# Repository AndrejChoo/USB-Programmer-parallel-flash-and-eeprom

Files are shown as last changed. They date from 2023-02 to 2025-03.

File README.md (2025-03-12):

# USB-Programmer-parallel-flash-and-eeprom
USB программатор параллельных Flash, EPROM, EEPROM, микроконтроллеров AVR (в том числе AT89CXX) в режиме высоковольтного параллельного программирования основанный на STM32.

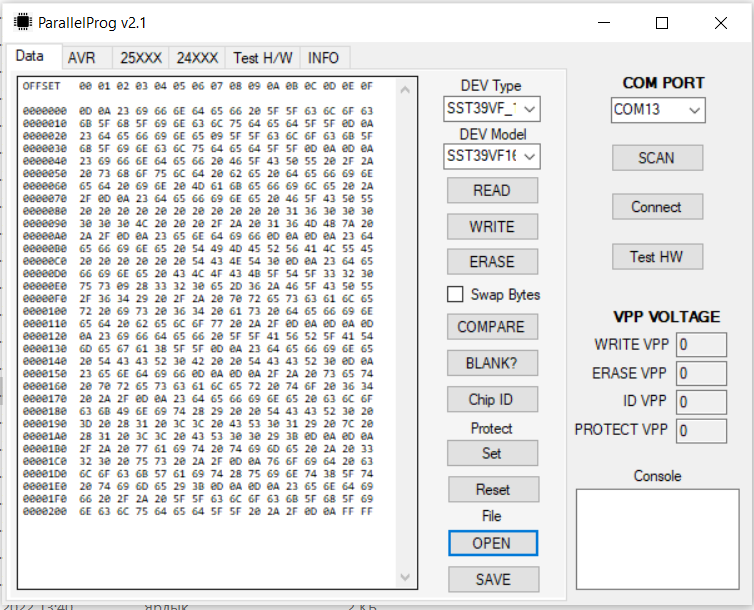
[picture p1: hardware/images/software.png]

# 9.04.2023
На данный момент исправлено множество ошибок в основном в прошивке платы-программатора. 
Немного доработан софт, исправлены некоторые ошибки во вкладке "TestH/W", также там добавлена функция проверки старшего байта данных (D15:8). Исправлена ошибка вылета программы при отключении COM порта (при нажатии на "Disconnect"). Но многие исключения до сих пор ещё не обрабатываются, например при введении некорректных данных в окошки с HEX числами.
Также добавлена прошивка для STM32F103Vxx (запускается также и на 103ZGT в 144 выводном корпусе). Возможно, добавлю прошивку для STM32F407V.
Мною на данный момент лично протестированы запись/чтение/стирание следующих чипов памяти:
8bit:
-W49F020;
-SST39VF040;
-AM29F040;
-W29C040;
-AT28C64;
16bit:
-MX29L3211;
-MX29LV320;
-SST39VF1601;
Протестирована работа программирования AVR в параллельном (высоковольтном) режиме, в том числе в 8-ногих корпусах.

# 10.04.2023
Добавлена поддержка:
8bit:
-W39V040 HUB Flash;
-AT49Fxxx;
16bit:
-M29Wxxx;
-S29ALxxx;
Микросхемы памяти любых семейств большего или меньшего объёма легко добавляются путём редактирования xml файлов в папке программатора.
Также теперь доступна возможность добавления новых чипов памяти без внесения изменений в код программы и прошивку программатора (каким образом это сделать, читайте в "help.txt" файле). Добавлять можно не любые чипы, а только те, у которых алгоритмы чтения/записи/стирания аналогичны с таковыми у уже поддерживаемых.

# 11.04.2023
Добавлена поддержка хабовой флешки PM29FLxxx.
Также навёл порядок в папке адаптеров, добавил к ним минимальное описание.

# 18.04.2023
Изменён алгоритм работы кнопки "Compare", теперь нет необходимости читать чип перед сравнением, это делается автоматически.
Добавлена функция "Blank check", теперь не надо рассматривать прочитанный hex на ячейки, отличные от 0xFF. Чтение также происходит автоматически по нажатию кнопки "Blank?".

# 19.04.2023
Добавлена функция "Swap Byte" для возможности менять местами каждые чётный и нечётный байт записываемого файла. Возможно пригодится для для работы с 16-битными флешками.

# 23.04.2023 
Добавлена поддержка EPROM 27C256/27C512. Работа с 256 проверена на однократно программируеммой AM27C256, работа с 512 пока в железе на проверена, теоретически должны шиться. Пока не добавлена функция стирания для электрически стираемых моделей типа W27C, SST27SF. Добавлю позже, когда получу рабочие образцы. Также должны работать и УФ стираемые модели при условии установки нужного уровня напряжения VPP. Платы переходников также добавлены в папку "PCB/Adapters". Будьте внимательны с джамперами.

# 26.04.2023
Переработал основную плату программатора: добавлен один джампер (переключение адресной линии А18 между А18 и VPP для программирования некоторых EPROM 27С в корпусе DIP32 в переходнике DIP32 для флешек 29x); добавлена разводка для транзисторных ключей управления напряжением VPP параллельно с разводкой под реле; и самое интересное - добавлена разводка для преобразователя напряжения от ШИМ самого микроконтроллера с возможностью контроля напряжения по АЦП для автоматической установки уровня напряжения VPP (параллельно сохранена разводка для преобразователя на MC34063). Схему, прошивки и софт пока готовлю к релизу. Всё будет работать и на старой версии платы.

# 2.05.2023
Добавлена обработка некоторых внештатных событий в программе для предотвращения её "аварийного" завершения.
Добавлен новый переходник DIP32 для EEPROM 27x010, 27x020, 27x040. Обновление софта и прошивки будут в ближайшее время, когда получу образцы для тестов.

# 3.05.2023
Проверена работа программатора с UV EPROM M27C256 и FM27C010 (новый адаптер DIP32  для EPROM). Всё шьётся отлично, внешнее питание VCC не потребовалось, прошивается и при 5 Вольтах. Прошивки и софт обновлены.

# 4.05.2023
Добавлен новый адаптер для 16-битных EPROM и EEPROM типа M27C800, MX29F1615 в корпусе DIP42. В софт и прошивку добавлена поддержка MX29F1615, позже добавлю поддержку M27С800, когда получу образец на тесты.

# 6.05.2023
Добавлена поддержка микроконтроллеров AT89C51/52 в режиме высоковольтного параллельного программирования. Также добавлен адаптер для данных микроконтроллеров в корпусе DIP40 и схема адаптера. 
Проверена работа с UV EPROM AM27C010 - прошивается корректно. 

# 7.05.2023
Добавлена поддержка микроконтроллеров AT89C1051/2051/4051. Также добавлен адаптер для этих МК в корпусе DIP20.

# 11.05.2023
На этот раз - масштабное обновление. Добавлен и опробован новый дискретный модуль повышающего DC-DC преобразователя с цифровым управлением для автоматической установки напряжения VPP. От идеи преобразователя на самом STM я решил отказаться, так как непрерывная коррекция напряжения отнимала бы валовую долю процессорного времени. Поэтому преобразователь был выполнен в виде отдельного модуля, который устанавливается на основную плату в виде "бутерброда" (смотрите инструкцию по модификации основной платы в папке "Hardware"). Позже добавлю новую разводку платы уже с новым преобразователем.
Софт и прошивки обновлены. Старые версии платы также будут без проблем работать с новым софтом и прошивками.
В программе добавлена новая функция во вкладке "Test HW", которая позволяет установить уровень напряжения VPP и проверить корректность его установки.
Работа нового преобразователя проверена на, наверное, самом "прожорливом" из имеющихся у меня чипе памяти MBM2764, который программируется при уровне VPP - 21 Вольт, прошился успешно. Также проверил работу на AT89C52, тоже всё отлично. Просадок напряжения во время процесса записи нет.

# 12.05.2023
Добавлена новая версия платы (v2.1) с разводкой под новый автоматический преобразователь напряжения. Также исправлены некоторые ошибки. Сделана разводка под транзисторные ключи для коммутации OE и A9 вместо реле (ещё не тестировал, разводка под реле осталась). Также подписал практически все компоненты.
Проверена работа с M27C2001 (2Mx8) - прошилась с первого раза без ошибок.

# 28.05.2023
Наконец-то окончательно избавился от реле. Теперь вместо реле используются транзисторные ключи, что значительно снижает помехи по питанию во время срабатывания реле. Работа опробована на самых требовательных к VPP микросхемах EPROM. Схему модификации смотрите в разделе "Hardware". В последних двух версиях платы разводка под ключи вместо реле уже есть.
Также была проверена работа с электрически стираемыми EEPROM SST27SF512, всё работает отлично. Должны также работать W27C512, они программируются точно также. К сожалению те образцы, что я получил от китайских "товарищей" с Али оказались нерабочими, так что проверить не на чем. 
Прошивка и софт остались прежними, за исключением файла "x27x512.xml", он дополнен новыми моделями микросхем памяти.

# 1.06.2023
Немного подкорректировал разводку последней версии платы: перенёс USB разъём на верхнюю сторону платы (разводка под разъём на нижней стороне также осталась). Правда, его расположение не очень удобное - на углу платы. Добавлены перемычки на пины питания для возможности установки STM32F407 (есть отличия по 1 пину на стороне 1-25). Также сделал по толще некоторые линии питания. Подправил кое-где маску. В остальном без изменений.

# 24.06.2023
Получил платы версии v2.1 с pcbway, собрал и протестировал. Это окончательный вариант платы, больше никаких изменений не будет. Фото платы есть в папке HARDWARE/IMAGES.

# 25.02.2024
Переписал софт на Qt. Теперь есть возможность использовать на Linux. Скомпилировал под Linux x64, Linux aarch64, Windows x64. В Qt версии не реализованы функции вкладки "Test HW". Для запуска на Linux необходимо установить QSerialport, qt-base. Возможно, потребуются ещё какие-то недостающие пакеты. Проверить не могу, так как у меня на всех ОС установлен Qt-creator со всем необходимым. Qt версия для Windows скомпилирована со статическими библиотеками, должна работать "из коробки".
Возможно, особенно на Fedora, будет необходимо предоставит права доступа к /dev/ttyACM0 - пишем в терминале: sudo chmod a+rw /dev/ttyACM0. На Windows Qt-версия работает точно так же, но мне больше нравится C# версия программы.

# 15.11.2024

Разработал упрощённую версию программатора на stm32f103c8t6.

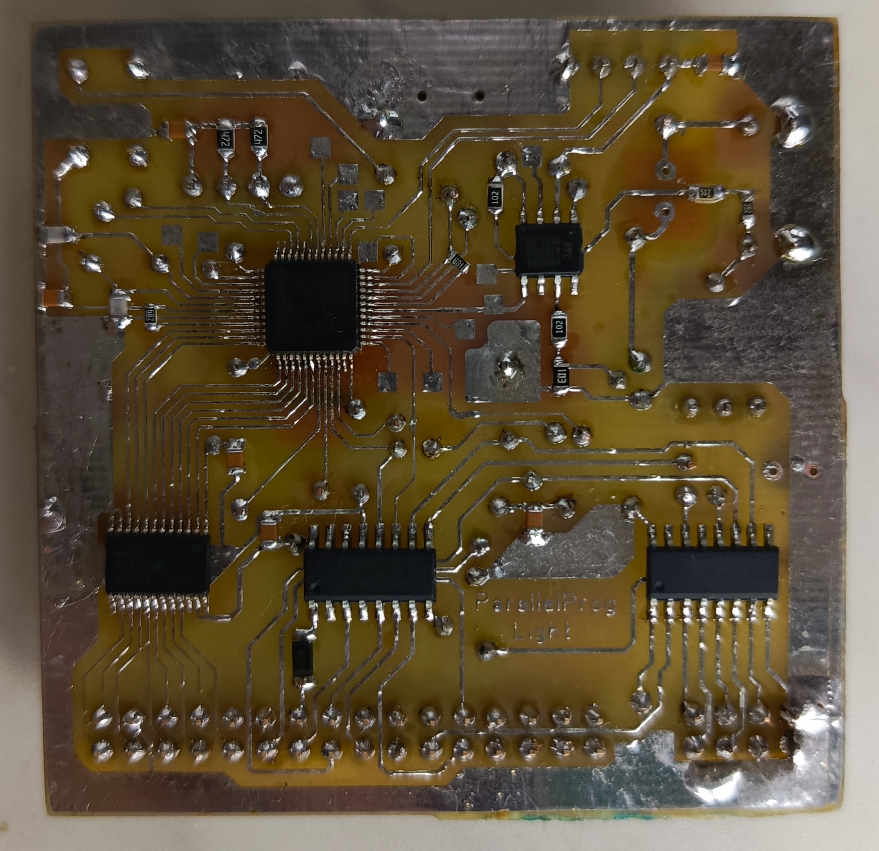
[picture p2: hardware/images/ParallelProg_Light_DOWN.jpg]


Для формирования шины адреса используются три сдвиговых регистра 74hc595. Шина данных только 8 бит, используется всего один буффер 74lvc8t245. Источник высокого напряжения аналогичный "полной версии" программатора - с автоматической установкой уровня VPP. Адаптеры также подходят от "большого брата", кроме 16-битных. Скорость работы программатора несколько ниже, чем у старшей версии ввиду нового последовательного метода формирования сигналов шины адреса, но не критично.
Функционал данной версии программатора, естественно, урезан. Поддерживаются только 8-битные микросхемы памяти. На данный момент прошивка находится в стадии разработки, пока поддерживаются только флешки типа W29Cxxx, AM29Fxxx и им подобные. Буду постепенно добавлять поддержку других микросхем памяти, в первую очередь УФ-стираемых EPROM.

# 18.11.2024

На сегодня в Light-версии программатора опробованы и работают: параллельные флешки W29CXXX, параллельные EEPROM AT28C64/C256, параллельные EEPROM W27C512 (должны работать и УФ-стираемые EPROM типа M27C512), I2C EEPROM серии 24ХХХ (на разъёме I2C). Не проверял, но должны работать флешки типа AM29F010/020/040, SST39F512/010/020/040, AT29FXXX и им подобные восьмибитные.

# 12.03.2025

Выкладываю 3D модели корпуса для полной версии программатора (для платы последней версии), которые разработал и поделился со мной Виктор Черневов. Фото и модели в папке "hardware/case_model".

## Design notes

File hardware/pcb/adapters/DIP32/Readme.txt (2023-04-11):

Адаптер подходит для:
W29CXXX
AM29FXXX
и других с аналогичной распиновкой.

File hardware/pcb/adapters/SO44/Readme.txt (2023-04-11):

Подходит для 16-битных флешек в узких длинных корпусах, например MX29LXXXX.
Перемычку на плате надо запаять к плюсу питания.

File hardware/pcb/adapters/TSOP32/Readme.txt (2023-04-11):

Подходит для флешек как в широком, так и в узком корпусах:
AT49FXXX
SST39SFXXX
и другим с аналогичной распиновкой.

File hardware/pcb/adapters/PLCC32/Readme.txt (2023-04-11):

Подходит для:
W29CXXX
AM29FXXX
AT49FXXX
и других с аналогичной распиновкой.

Джампер в открытом состоянии используется для флешек, у которых вместо A18 - RESET и наоборот.

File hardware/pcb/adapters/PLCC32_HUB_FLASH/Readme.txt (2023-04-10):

Адаптер для хабовых флешек, типа W39Vxxx и им подобных.
При изготовлении платы ЛУТ-ом или фоторезистом - изображение зеркалить!

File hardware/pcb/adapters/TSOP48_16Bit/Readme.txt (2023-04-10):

Адаптер для 48-ногих флешек в корпусе TSOP48 (например, M29W160,S29AL016 и т.д.).
Адаптер сделан для китайского переходника с колодки-быстросъёма на DIP48 (см. фото).
При изготовлении платы ЛУТОМ или фоторезистом изображение не зеркалить, дорожки нарисованы с 
нижней стороны платы.
На плате установлен джампер, переключающий контакт RESET между VCC и VPP. Напряжение VPP нужно для 
снятия защиты с BOOT-блоков некоторых моделей памяти (например, MX29LV320).

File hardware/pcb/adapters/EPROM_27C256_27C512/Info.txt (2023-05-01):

Адаптер DIP28 подходит для 27с64, 27с128, 27с256 (джампер в должны быть установлены в положение "256"), 
для 27с512 (джампер в в положении "512").

Будьте внимательны с джамперами! Их неправильная установка может вывести из 
строя программируемую микросхему!
Внешнее питание к адаптеру подключать не обязательно, некоторые микросхемы памяти программируются
и без повышения VCC (как по datasheet-у).

Напряжение программирования VPP для eprom от разных производителей может отличаться (от 12 вольт до 21,5 вольта).
Необходимый уровень VPP необходимо установит переключением перемычки питания на программаторе либо подбором 
номиналов резисторов преобразователя напряжения.

Резисторы на платах адаптеров в цепи внешнего питания нужно подбирать для получения нужного уровня VCC. Смотрите 
онлайн калькулятор для ams1117-adj.

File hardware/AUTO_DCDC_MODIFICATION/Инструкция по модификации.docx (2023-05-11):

Изначально у меня была идея сделать повышающий преобразователь ресурсами STM-ки, но оказалось, что из-за необходимости частой коррекции уровня напряжения – это бы отнимало валовую часть процессорного времени и тормозило бы процесс программирования непредсказуемым образом.

Поэтому было решено сделать отдельный преобразователь напряжения на микроконтроллере, управляемому по цифровому интерфейсу.

Результат получился отличный. Теперь для установки напряжения нет необходимости менять какие-либо перемычки или подбирать резисторы. Всё происходит автоматически.

Для преобразователя напряжения я выбрал МК STC8G1K08A, так как он очень дёшев, прошивается через обычный USB-UART переходник, имеет компактный SOIC8 корпус.

Преобразователь выполнен на отдельной платке, которая припаивается на основную плату в виде «бутерброда» (см. фото). Для этого необходимо удалить компоненты DC-DC преобразователя на MC34063 с платы (если они установлены), которые расположены в зоне размещения «платки-бутерброда» (см. фото “MOD_Instruct”). Припаять платку преобразователя к основной плате с верхней стороны (там, где расположены разъёмы адаптеров и реле) в точках крепления, обозначенных красным цветом. Три точки (RX,3.3V и RST) необходимо припаять к основной плате проводами в точках, указанных на схеме.

Плата-преобразователь изготовлена в основном на SMD компонентах (кроме электролитов и транзистора). Самое важное при изготовлении – это подобрать правильный дроссель. У меня установлена SMD-гантелька с ~35 витками провода 0,2-0,3 мм. Транзистор в SOT-23 корпусе не сможет раскачать хороший дроссель и скорее всего не даст поднять напряжение выше10-15 вольт, поэтому лучше ставить в корпусе ТО92 (на плате есть разводка под оба корпуса). Диод – любой Шоттки или Fast в подходящем корпусе.

Микроконтроллер прошивается с помощью программы «stc-isp», которую можно скачать на сайте stc-micro через любой USB-UART переходник. При прошивке необходимо установить частоту ядра МК на 30MHz и снять галочку с «Reset pin used as I/O port» (см. картинку “PRG_SETTINGS”). МК можно заменить на более ёмкий STC8G1K17A с той же прошивкой.

Для тестирования работы преобразователя во вкладке тестов основной программы добавлена новая функция установки VPP.

Позже перерисую основную плату сразу с новым преобразователем напряжения на борту.

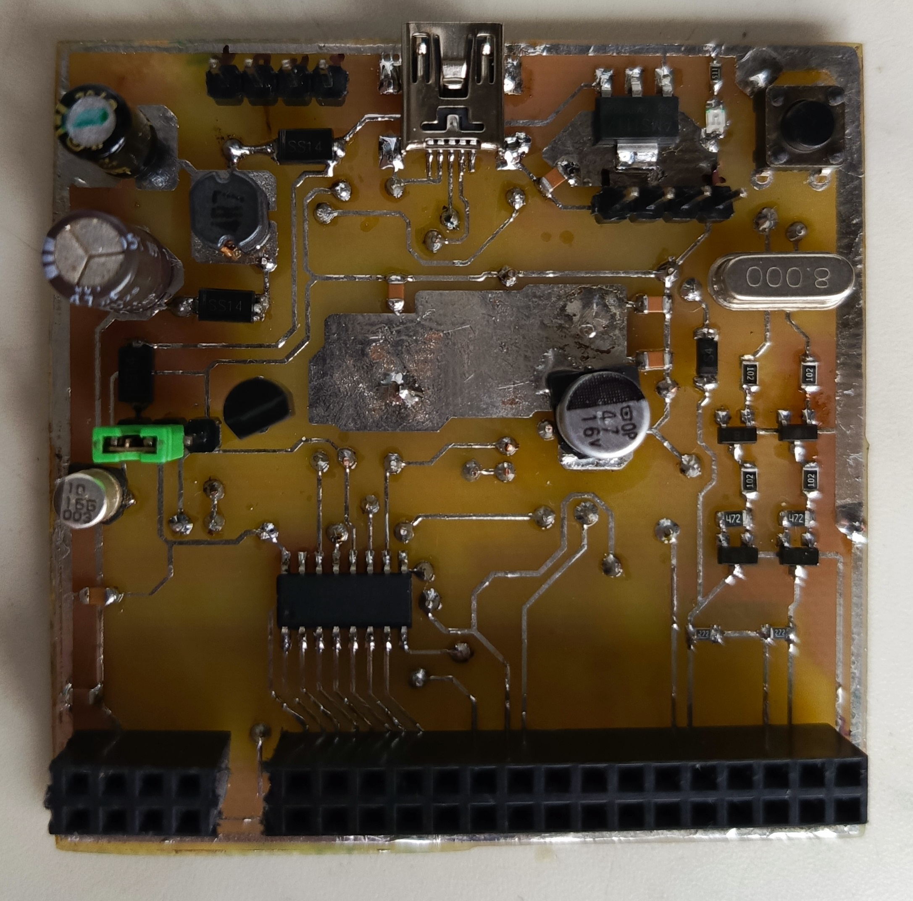
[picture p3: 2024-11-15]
hardware/images/ParallelProg_Light_UP.jpg

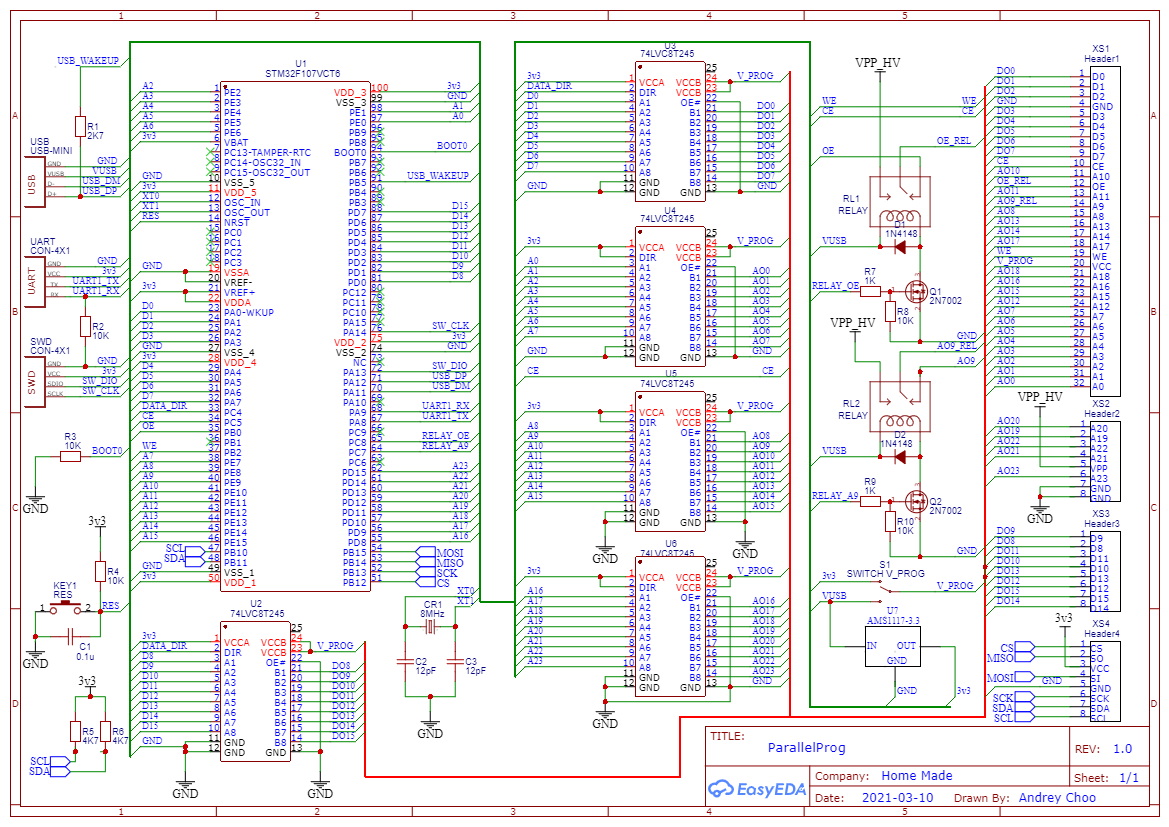
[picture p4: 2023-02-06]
hardware/images/Schematic_ParallelProg_2021-04-04.png

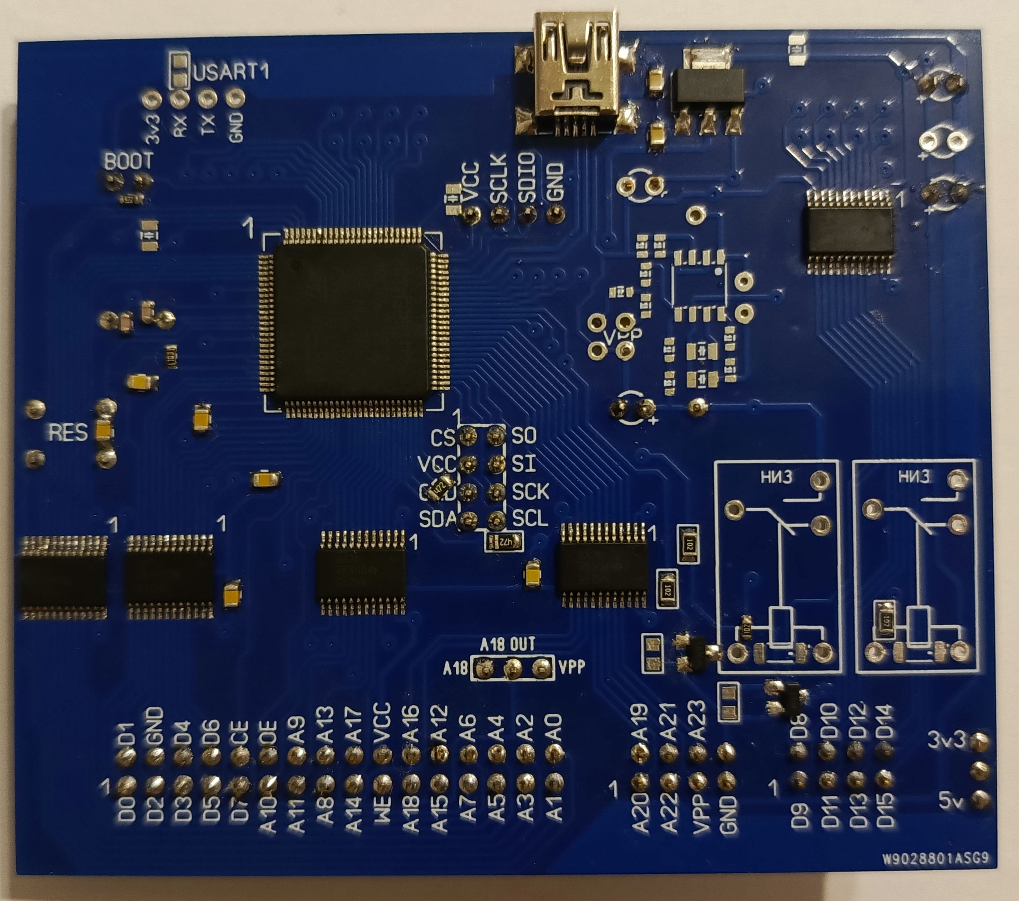
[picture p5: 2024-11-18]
hardware/images/ParallelProg_v2_0_Down.jpg

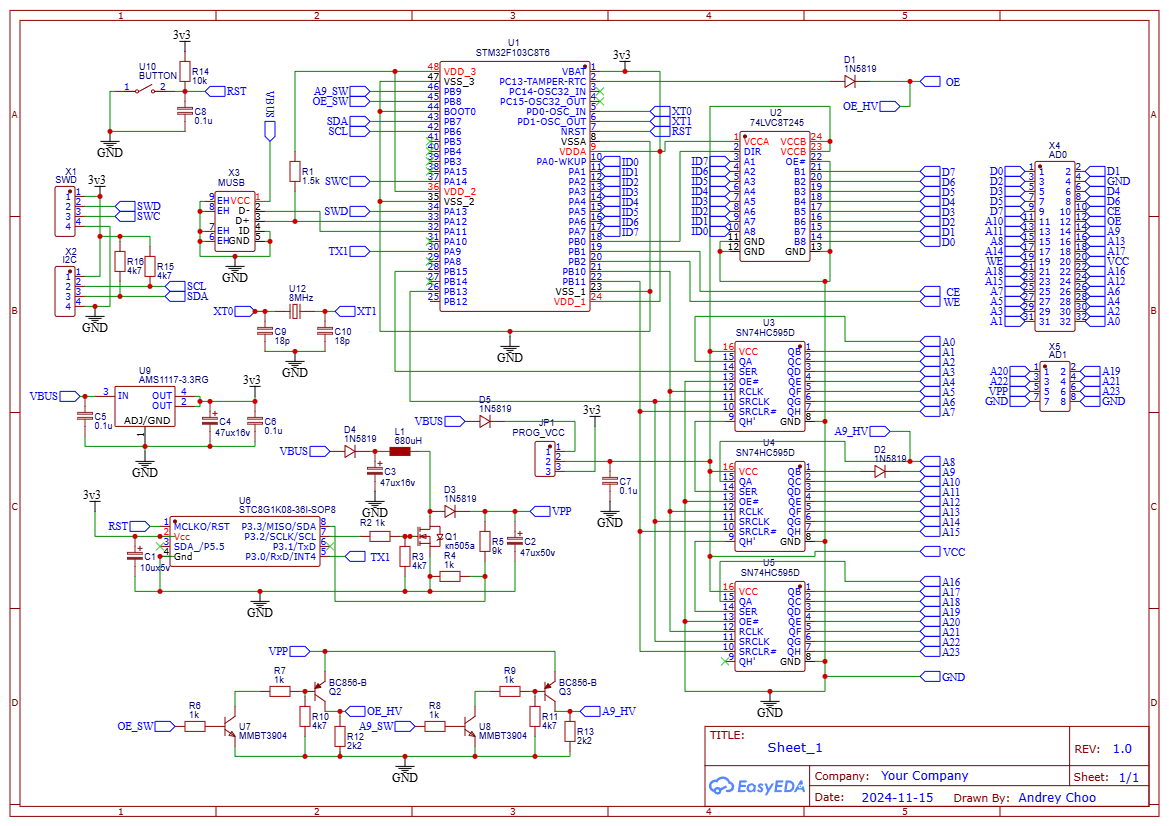
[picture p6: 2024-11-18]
hardware/images/Schematic_ParallelProg_Light_2024-11-18.png

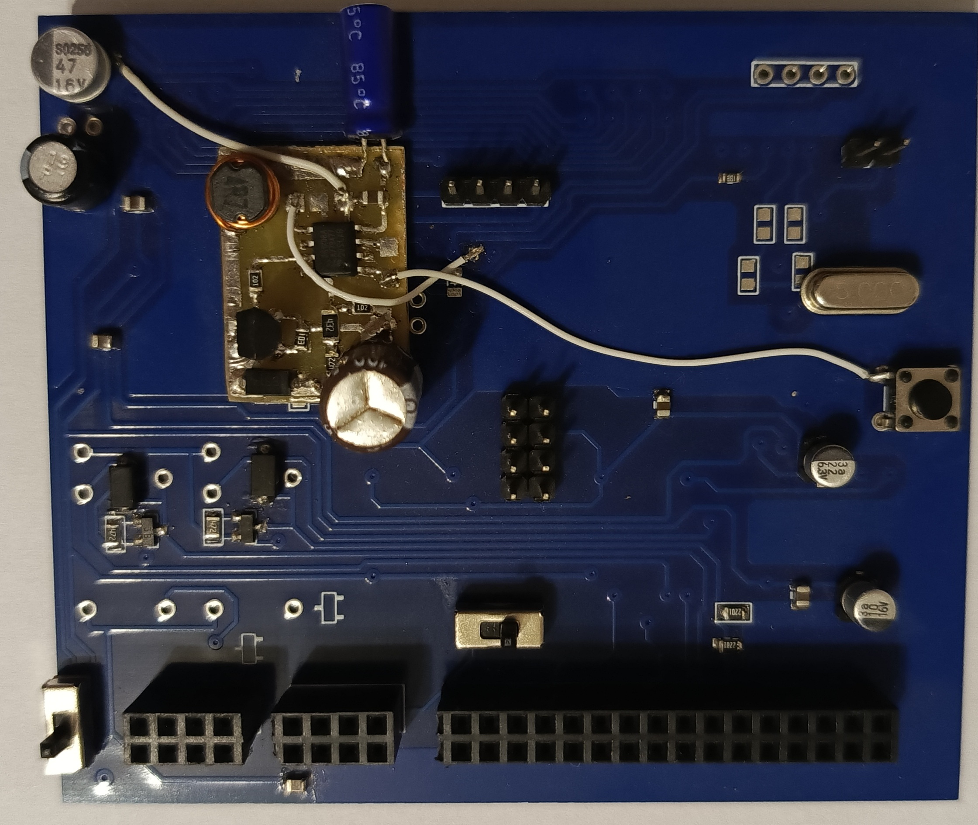
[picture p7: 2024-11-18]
hardware/images/ParallelProg_v2_0_Up.jpg

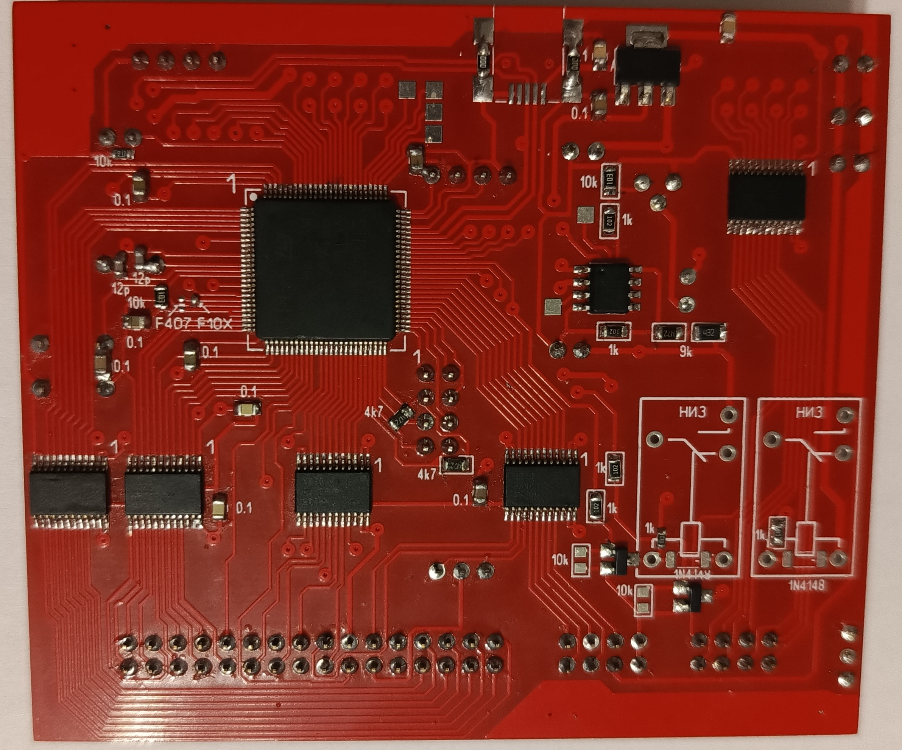
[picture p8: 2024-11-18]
hardware/images/ParallelProg_v2_1_Down.jpg

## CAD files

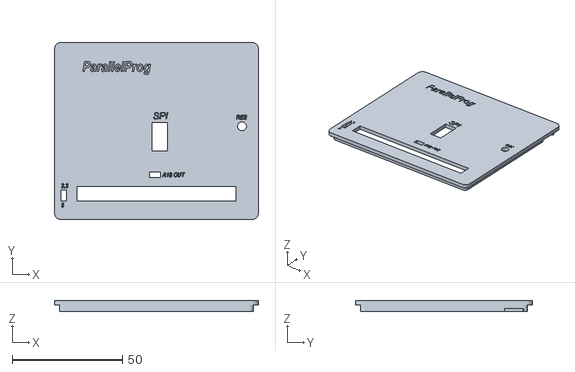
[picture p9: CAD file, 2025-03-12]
hardware/Case_model/Крышка Prog.STL
92.5 x 80.3 x 5.00

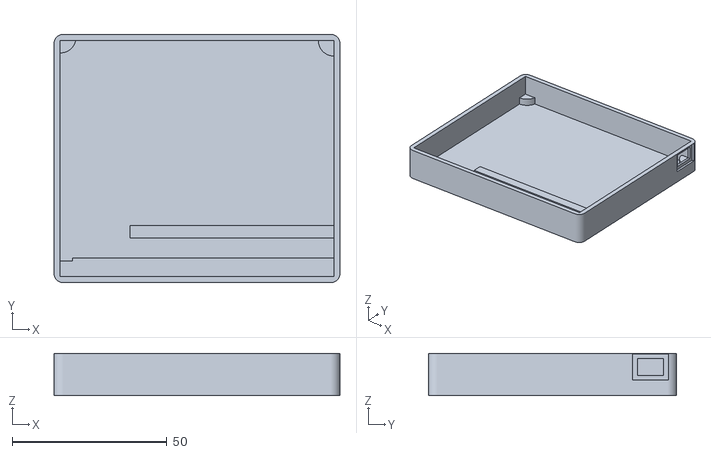
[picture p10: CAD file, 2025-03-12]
hardware/Case_model/Корпус Prog.STL
92.5 x 80.3 x 13.6

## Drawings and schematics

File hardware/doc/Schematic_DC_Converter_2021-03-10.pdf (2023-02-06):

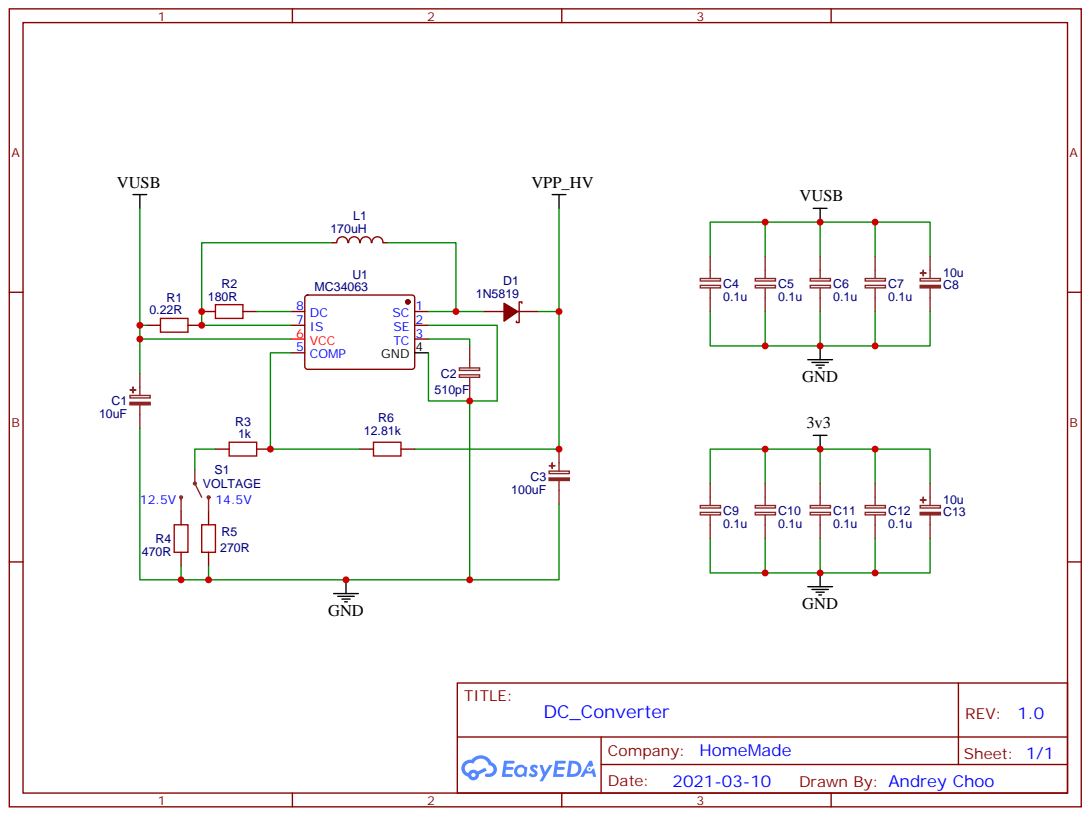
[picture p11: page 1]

Drawn By: Andrey Choo

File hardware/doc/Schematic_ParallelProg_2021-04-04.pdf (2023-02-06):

VDD_1 50 PB12 51 PB13 52 PB14 53 PB15 54 PD8 55 PD9 56 PD10 57 PD11 58 PD12 59 PD13 60 PD14 61 PD15 62 PC6 63 PC7 64 PC8 65 PC9 66 PA8 67 PA9 68 PA10 69 PA11 70 PA12 71 PA13 72 NC 73 VSS_2 74 VDD_2 75 PA14 76 PA15 77 PC10 78 PC11 79 PC12 80 PD0 81 PD1 82 PD2 83 PD3 84 PD4 85 PD5 86 PD6 87 PD7 88 PB3 89 PB4 90 PB5 91 PB6 92 PB7 93 BOOT0 94 PB8 95 PB9 96 PE0 97 PE1 98 VSS_3 99 VDD_3 100

# USBUSB

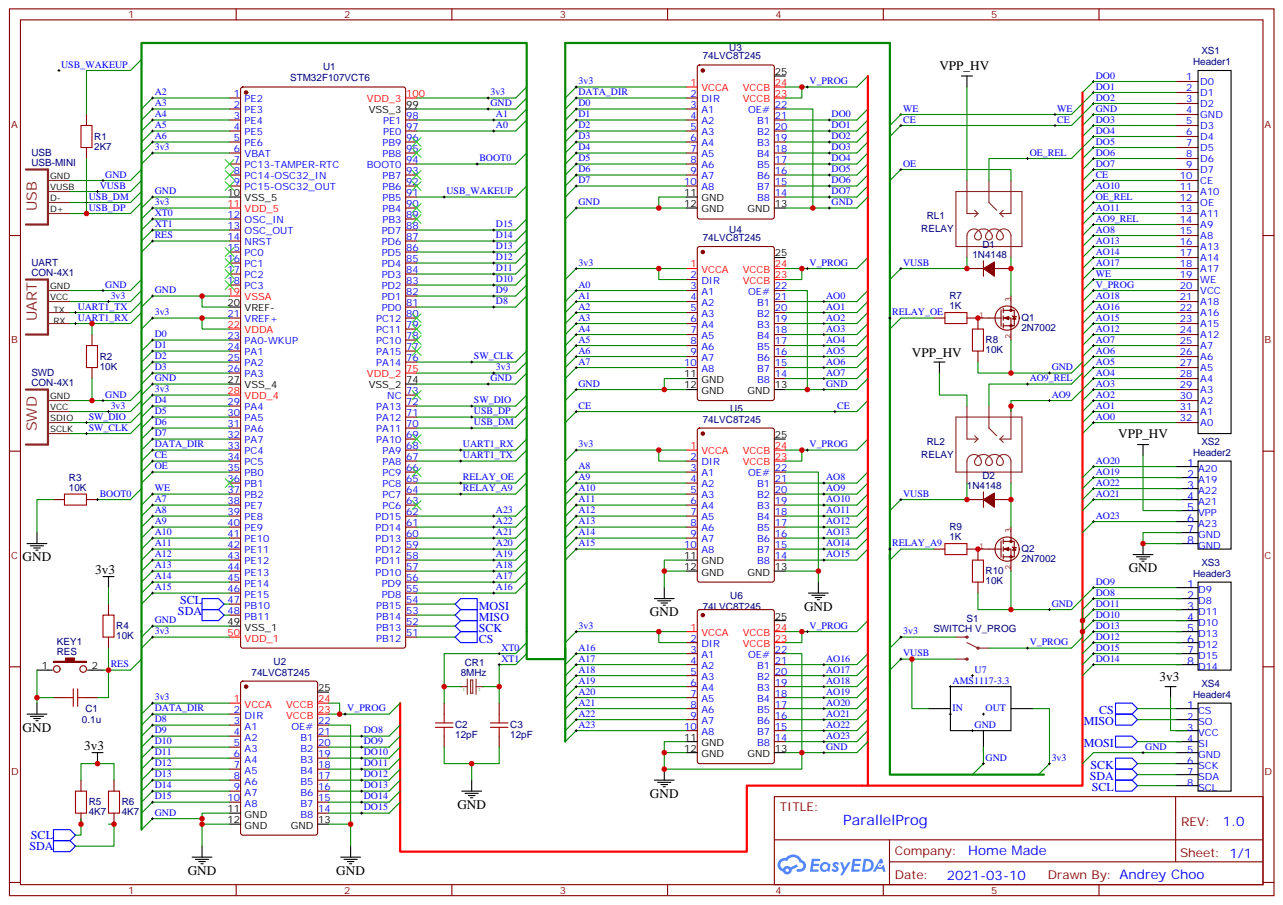
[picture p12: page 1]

Drawn By: Andrey Choo

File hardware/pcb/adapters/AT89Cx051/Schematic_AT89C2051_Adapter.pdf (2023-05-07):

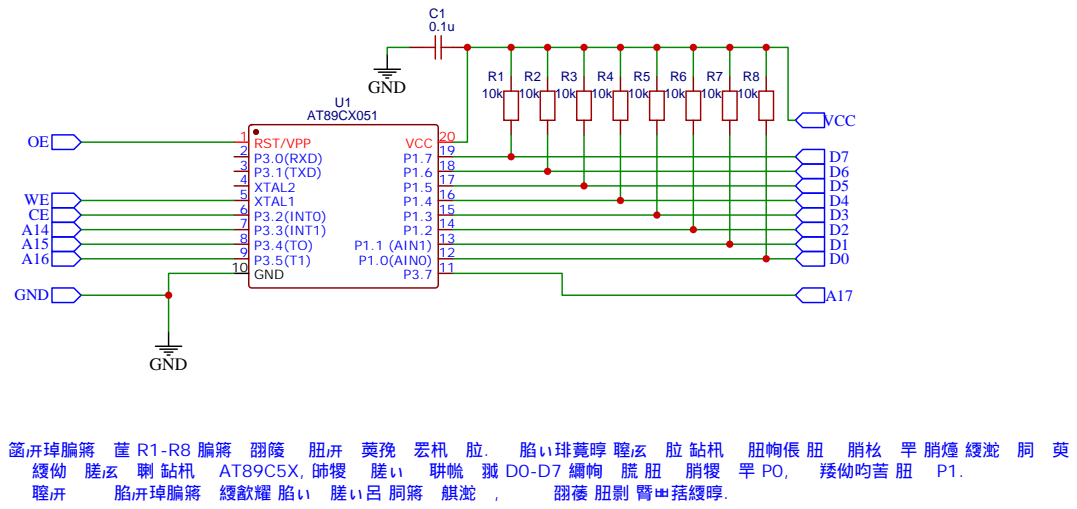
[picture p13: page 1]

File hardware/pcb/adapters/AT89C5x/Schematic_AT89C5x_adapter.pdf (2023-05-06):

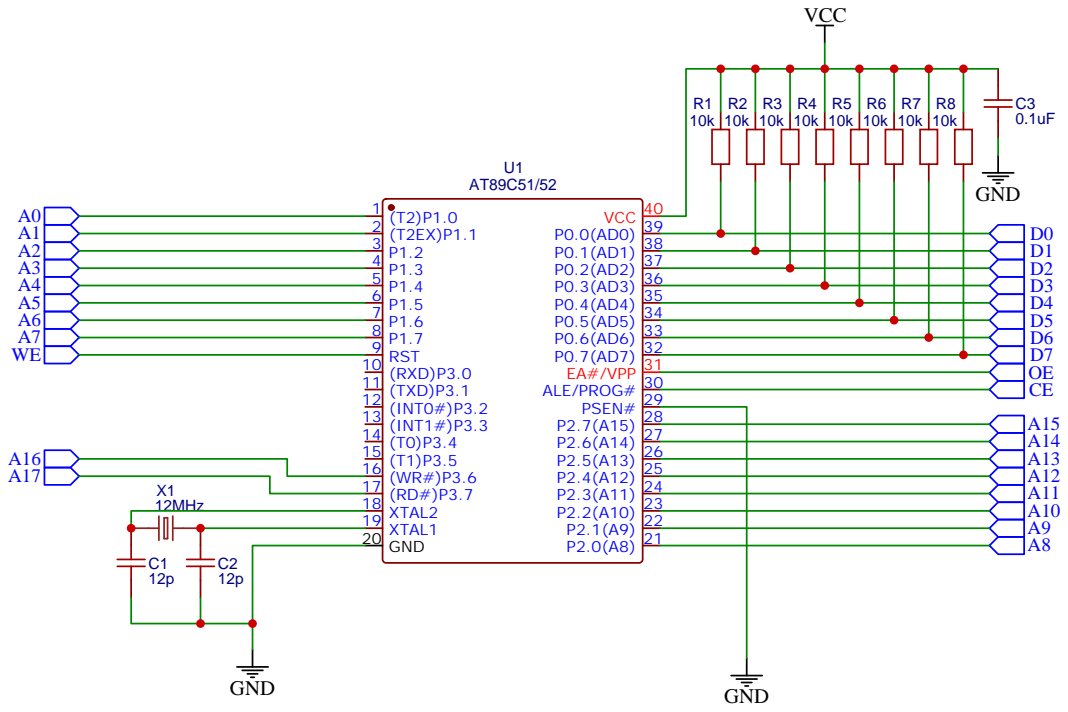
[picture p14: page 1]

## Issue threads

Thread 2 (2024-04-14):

nand flash

v6760hu, 2024-04-14:
https://github.com/bbogush/nand_programmer
Can I read nand flash

AndrejChoo, 2024-04-14:
Hi. NAND flash not supported, only parallel flash and eeprom.

v6760hu, 2024-04-14:
Using pin stm32f407vet6 i2c 93 and 92 serial ports to communicate with the upper computer will be faster. Because I saw Nano adopting this fast read and write solution.

AndrejChoo, 2024-04-14:
I do not think so. My device uses a hardware USB as a virtual com port, it uses bulk endpoints, and they are the fastest.

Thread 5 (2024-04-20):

Can you share the schematic diagram of tsop48? I would like to change it to a picture like this

v6760hu, 2024-04-20:
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

AndrejChoo, 2024-04-20:
I added the image to the "hardware/pcb/adapters/TSOP48_16Bit" folder.

v6760hu, 2024-04-21:
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
Unable to find this schematic diagram

AndrejChoo, 2024-04-21:
I don't have a schematic diagram of this adapter. All its DIP lines match the TSOP lines pin to pin.

v6760hu, 2024-04-21:
There are still a few unknown pins to link to the main control
![Uploading QQ截图20240421143829.png…]()

v6760hu, 2024-04-21:
![Uploading QQ截图20240421143829.png…]()

v6760hu, 2024-04-21:
![Uploading 7.png…]()

v6760hu, 2024-04-21:
Send me your email and I will send you the schematic and PCB source files. Can you help me take a look

v6760hu, 2024-04-21:
You can use https://easyeda.com/ Import

AndrejChoo, 2024-04-21:
andrejchukov@yandex.ru

v6760hu, 2024-04-21:
It has already been sent over

v6760hu, 2024-04-21:
Import with professional version

?凡事↗都飞
***@***.***

&nbsp;

------------------&nbsp;原始邮件&nbsp;------------------
发件人:                                                                                                                        "AndrejChoo/USB-Programmer-parallel-flash-and-eeprom"                                                                                    ***@***.***&gt;;
发送时间:&nbsp;2024年4月21日(星期天) 下午2:45
***@***.***&gt;;
***@***.******@***.***&gt;;
主题:&nbsp;Re: [AndrejChoo/USB-Programmer-parallel-flash-and-eeprom] Can you share the schematic diagram of tsop48? I would like to change it to a picture like this (Issue #5)

Which ones, for example?

—
Reply to this email directly, view it on GitHub, or unsubscribe.
You are receiving this because you authored the thread.Message ID: ***@***.***&gt;

AndrejChoo, 2024-04-21:
I have not received an email

v6760hu, 2024-04-21:
***@***.***&nbsp;&nbsp;Is this correct? Sent through multiple email addresses.

?凡事↗都飞
***@***.***

&nbsp;

------------------&nbsp;原始邮件&nbsp;------------------
发件人:                                                                                                                        "AndrejChoo/USB-Programmer-parallel-flash-and-eeprom"                                                                                    ***@***.***&gt;;
发送时间:&nbsp;2024年4月21日(星期天) 下午3:52
***@***.***&gt;;
***@***.******@***.***&gt;;
主题:&nbsp;Re: [AndrejChoo/USB-Programmer-parallel-flash-and-eeprom] Can you share the schematic diagram of tsop48? I would like to change it to a picture like this (Issue #5)

I have not received an email

—
Reply to this email directly, view it on GitHub, or unsubscribe.
You are receiving this because you authored the thread.Message ID: ***@***.***&gt;

AndrejChoo, 2024-04-21:
Your font is not displayed correctly. I see this.
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

v6760hu, 2024-04-21:
Have you not received the PCB file I sent you yet

AndrejChoo, 2024-04-21:
No, I didn't get it. Try sending to: andrejchukov@gmail.com

DRCRecoveryData, 2024-05-19:
> Have you not received the PCB file I sent you yet

can you sent me too?

hanaloginstruments@gmail.com

v6760hu, 2024-05-19:
没有收到

?凡事↗都飞
***@***.***

&nbsp;

------------------&nbsp;原始邮件&nbsp;------------------
发件人:                                                                                                                        "AndrejChoo/USB-Programmer-parallel-flash-and-eeprom"                                                                                    ***@***.***&gt;;
发送时间:&nbsp;2024年5月19日(星期天) 下午2:01
***@***.***&gt;;
***@***.******@***.***&gt;;
主题:&nbsp;Re: [AndrejChoo/USB-Programmer-parallel-flash-and-eeprom] Can you share the schematic diagram of tsop48? I would like to change it to a picture like this (Issue #5)

Have you not received the PCB file I sent you yet

can you sent me too?

***@***.***

—
Reply to this email directly, view it on GitHub, or unsubscribe.
You are receiving this because you authored the thread.Message ID: ***@***.***&gt;

DRCRecoveryData, 2024-05-19:
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

Not yet can yoy sent via my email
